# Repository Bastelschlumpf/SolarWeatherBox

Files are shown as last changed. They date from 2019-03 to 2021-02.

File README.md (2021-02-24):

## SolarWeatherBox
  **Iot Weather sensor with solar power and sending the data to an MQTT server.***

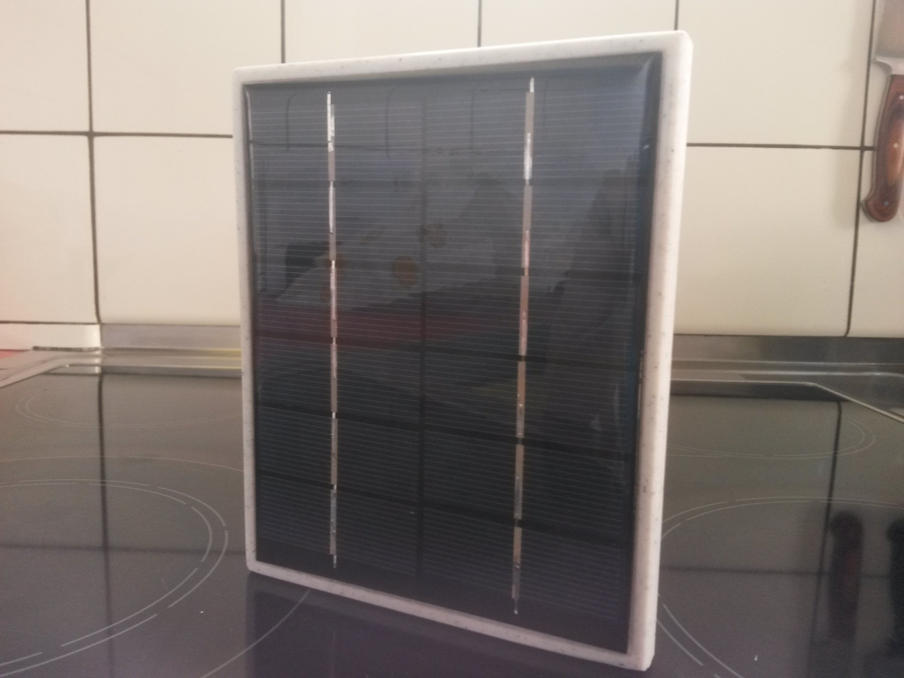
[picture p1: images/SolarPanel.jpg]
SolarPanel
   

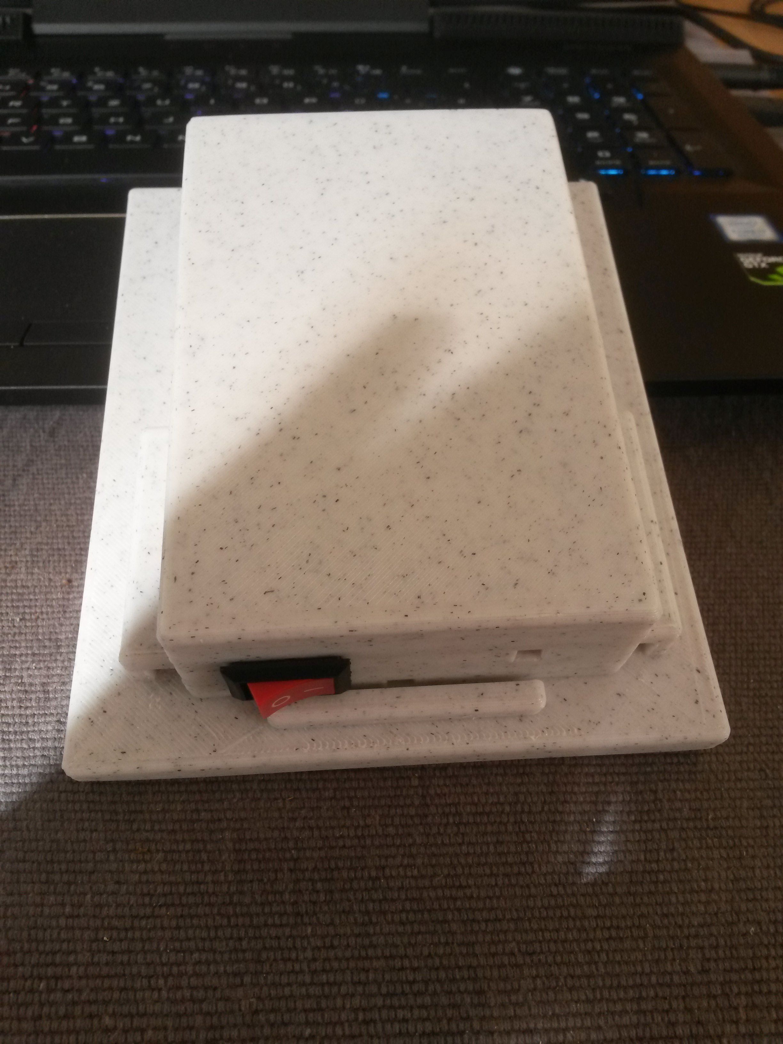
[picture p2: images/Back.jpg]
SolarWeatherBox
   

   SolarWeatherBox BoxInternal

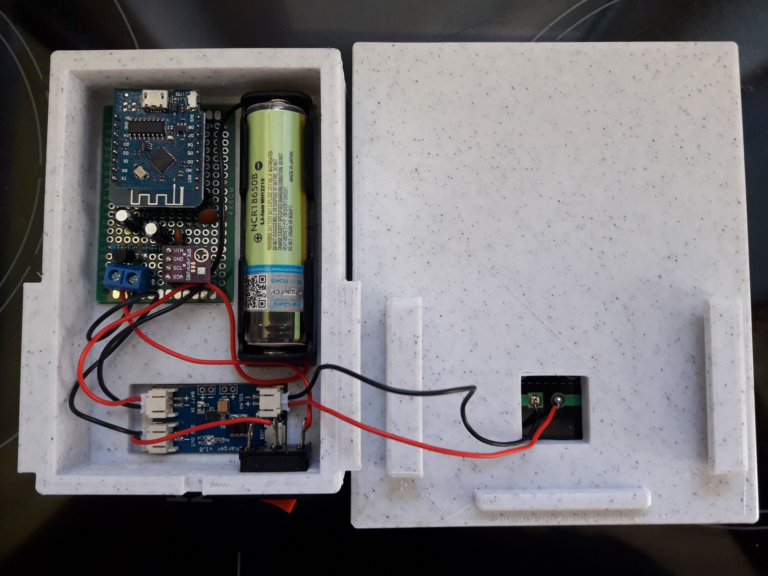
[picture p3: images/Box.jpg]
SolarWeatherBox Box
   

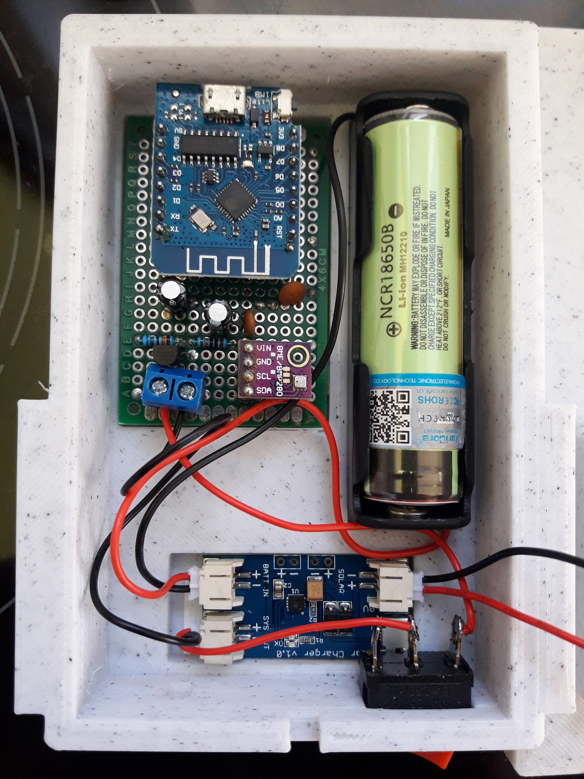
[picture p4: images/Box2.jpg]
SolarWeatherBox Box2
   

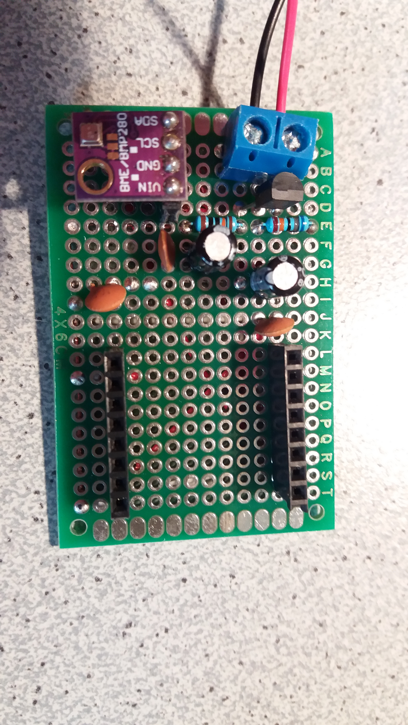
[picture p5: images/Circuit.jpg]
SolarWeatherBox Circuit
   

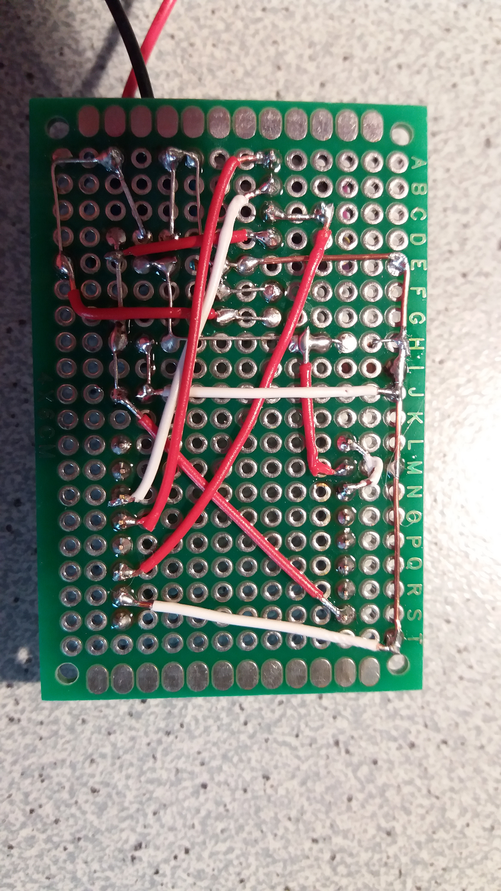
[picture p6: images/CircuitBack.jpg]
SolarWeatherBox CircuitBack
   

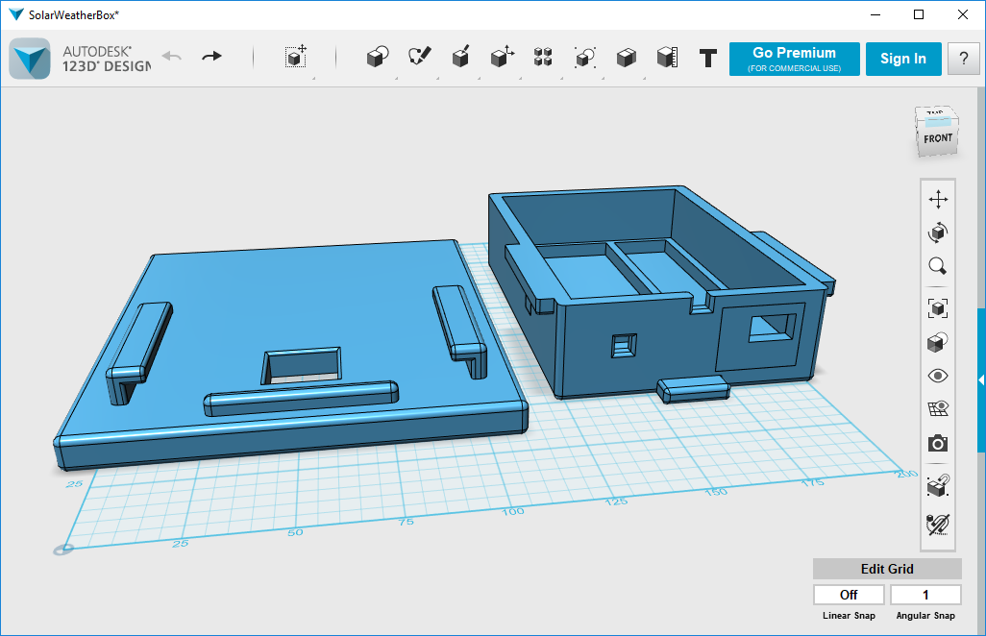
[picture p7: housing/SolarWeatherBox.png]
Housing
   

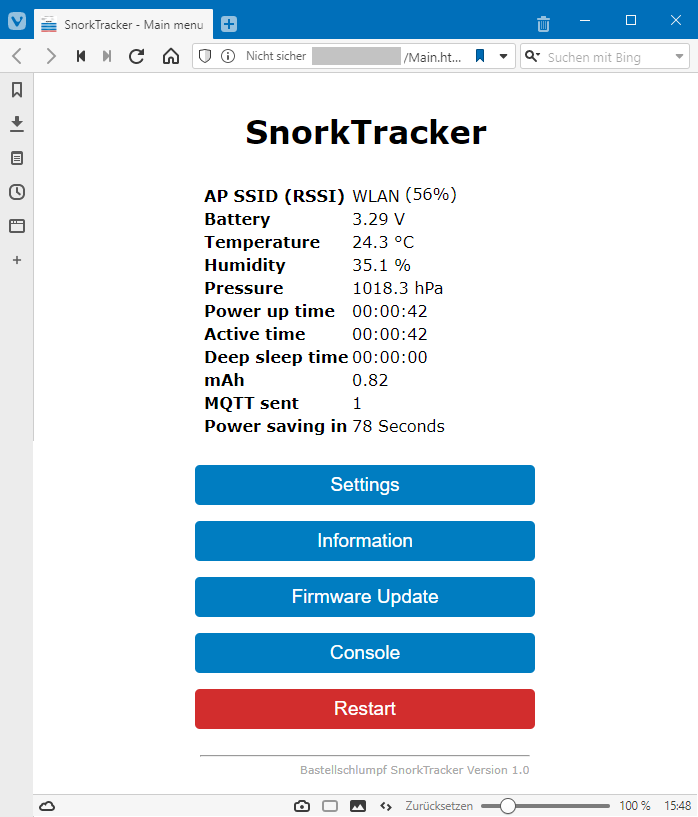
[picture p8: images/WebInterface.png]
Circuit WebInterface
   

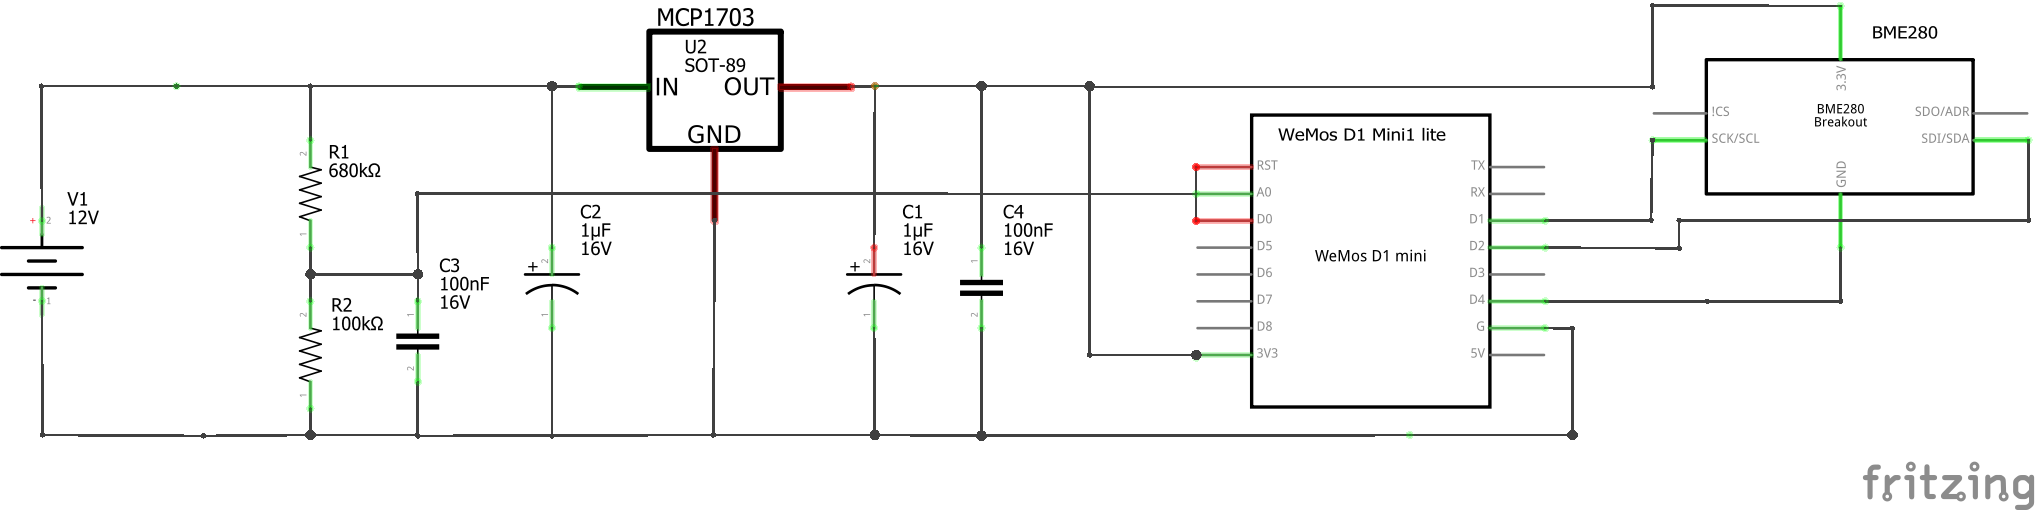
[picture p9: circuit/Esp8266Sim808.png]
Circuit
   

### Description

### Disclaimer
   I don't take any responsibility nor liability for using this software nor for the 
   installation or any tips, advice, videos, etc. given by any member of this site or any related site.

### License
   This program is licensed under GPL-3.0

### Source Code
-  The software is the similar to Snorktracker

### Shopping list
Here are some sample shopping items. Please check the details if everything is correct.

|Label |Price |Sample URL |
|---|---|---|
|Switch |1€ | https://www.bastelgarage.ch/kippschalter-on-off-schalter-6a-125v-3a-250v?search=schal |
|WeMos D1 Mini lite |7€ | https://www.amazon.de/1-0-0-WIFI-Internet-Things-Development-ESP8285/dp/B07JBK1SWQ |
|BME280 |6€ | https://www.amazon.de/AZDelivery-GY-BME280-Barometrischer-Temperatur-Luftfeuchtigkeit/dp/B07FS95JXT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 |
|Li-Ion Akku |12€ | https://www.bastelgarage.ch/li-ion-akku-3000ma-18650-mit-schutzelektronik-und-stecker |
|Solar Set |19€ | https://www.bastelgarage.ch/solar-set-2w-lolin32-mit-laderegler-fur-lipo-akku |

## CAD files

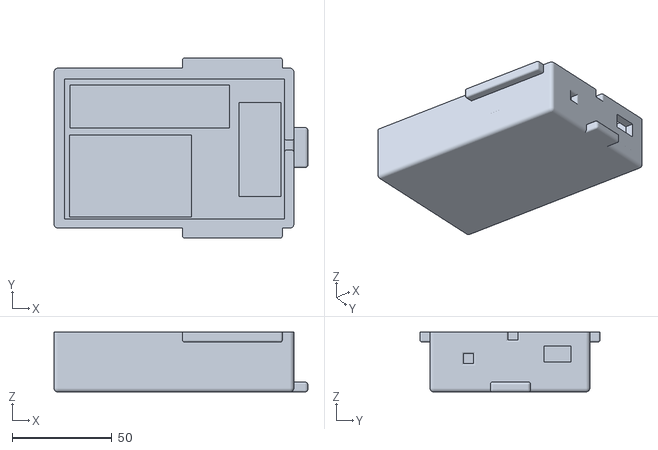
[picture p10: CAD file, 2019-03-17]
housing/SolarBox.stl
127.1 x 90.0 x 30.0

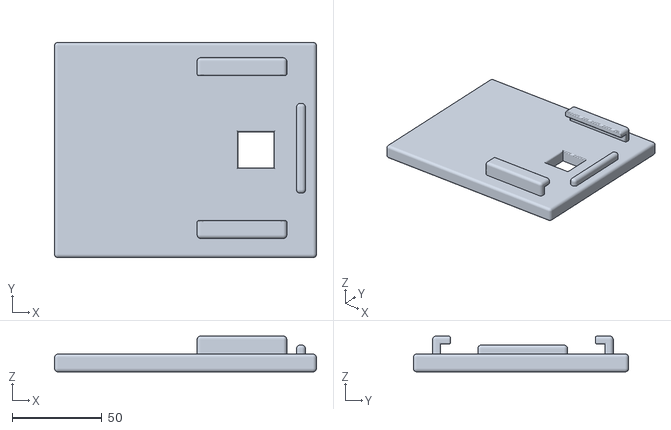
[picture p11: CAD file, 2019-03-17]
housing/SolarPanel.stl
146.0 x 120.0 x 20.0

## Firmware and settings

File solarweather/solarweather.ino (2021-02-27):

/*
   Copyright (C) 2021 SFini

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
   You should have received a copy of the GNU General Public License
   along with this program.  If not, see <http://www.gnu.org/licenses/>.
*/
/**
  * @file tracker.ino 
  *
  * Main file with setup() and loop() functions
  */


#include <SoftwareSerial.h>
#include <ArduinoOTA.h>
#include <FS.h>

#include "Config.h"
#define USE_CONFIG_OVERRIDE //!< Switch to use ConfigOverride
#ifdef USE_CONFIG_OVERRIDE
  #include "ConfigOverride.h"
#endif

#include "Utils.h"
#include "StringList.h"
#include "Options.h"
#include "Data.h"
#include "Voltage.h"
#include "DeepSleep.h"
#include "WebServer.h"
#include "Mqtt.h"
#include "BME280.h"


MyOptions   myOptions;                       //!< The global options.
MyData      myData;                          //!< The global collected data.
MyVoltage   myVoltage   (myOptions, myData); //!< Helper class for deep sleeps.
MyDeepSleep myDeepSleep (myOptions, myData); //!< Helper class for deep sleeps.
MyWebServer myWebServer (myOptions, myData); //!< The Webserver
MyBME280    myBME280    (myOptions, myData); //!< Helper class for the BME280 sensor communication.

MyMqtt      myMqtt(MyWebServer::server.wifiClient(), myOptions, myData); 

bool        isStarting  = false;             //!< Are we in a starting process?
bool        isStopping  = false;             //!< Are we in a stopping process?

/**
 * ***** IMPORTANT *****
 * It seems that the yield function of ESP does not feed the watch dog timer.
 * So we overwrite the yield() function here. If not the program crashed on some waits.
 * ***** IMPORTANT *****
 */
 /*
void yield(void)
{
   ESP.wdtFeed();
}*/

/** Overwritten Debug Function 
  * It logs all the debug calls to the console string-list
  * And call a refresh of the webserver for not blocking the system.
  */
void myDebugInfo(String info, bool fromWebserver, bool newline)
{
   static bool lastNewLine = true;
   
   if (newline || lastNewLine != newline) {
      String secs = String(myData.getActiveTimeSec()) + F(": ");

      myData.logInfos.addTail(secs + info);
      if (!lastNewLine) {
         Serial.println("");
      }
      Serial.println(secs + info);
   } else {
      String tmp = myData.logInfos.removeTail();

      Serial.print(tmp + info);
      myData.logInfos.addTail(tmp + info);
   }
   lastNewLine = newline;

   if (!fromWebserver) {
      myWebServer.handleClient();   
      myWebServer.handleClient();   
      myWebServer.handleClient();   
   } 
   delay(1);
   yield();
}

/** Overwritten delay loop for refreshing the webserver on waiting processes. */
void myDelayLoop()
{
   myWebServer.handleClient();   
   myWebServer.handleClient();   
   myWebServer.handleClient(); 
   delay(1);
   yield();
}

/** Main setup function. This is also called after every deep sleep. 
  * Do the initialization of every sub-component. */
void setup() 
{
   Serial.begin(115200); 
   delay(1000);

   MyDbg(F("Start SolarWeather ..."));

   SPIFFS.begin();
   myOptions.load();

   // Back to deep sleep?
   myDeepSleep.begin();
   if (myDeepSleep.haveToSleep()) {
      myDeepSleep.sleep();
   } else { // no deep sleep!
      myVoltage.begin();
      myWebServer.begin();
      myMqtt.begin();
      myBME280.begin();
   }
}

/** Main loop function.
  * Read the power supply voltage.
  * Checks for OTA activities.
  * Starts the deep sleep mode if needed.
  */
void loop() 
{
   myVoltage.readVoltage();
   myBME280.readValues();
   myDeepSleep.updateTimeToSleep();

   myWebServer.handleClient();
   
   if (myData.isOtaActive) {
      ArduinoOTA.handle();    
   }

   if (myOptions.isMqttEnabled) {
      myMqtt.handleClient();
   }

   if (!myMqtt.waitingForMqtt()) {
      if (myDeepSleep.haveToSleep()) {
         myDeepSleep.sleep();
      }
   }

   yield();
   delay(10); 
}

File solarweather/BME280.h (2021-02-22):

/*
   Copyright (C) 2021 SFini

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
   You should have received a copy of the GNU General Public License
   along with this program.  If not, see <http://www.gnu.org/licenses/>.
*/
/**
  * @file BME280.h
  * 
  * Class to communicate with the BME280 module.
  */


#include <Adafruit_BME280.h>

#define PIN_BME_GRND      D4      //!< Ground pin to the BME280 module

#define BARO_CORR_HPA     34.5879 //!< Correction for 289m above sea level
#define TEMP_CORR_DEGREE  -2.0    //!< The BME280 measure 2 degrees too high 


/**
  * Communication with the BME280 modul to read temperature, humidity and pressure
  */
class MyBME280
{
protected:
   MyOptions      &myOptions;    //!< Reference to global options
   MyData         &myData;       //!< Reference to global data
   int             pinGrnd;      //!< Ground-Pin connection to switch on the BME280 module
   uint8_t         portAddr;     //!< Port address of the bme280
   Adafruit_BME280 bme280;       //!< Adafruit BME280 helper interface
   
public:
   MyBME280(MyOptions &options, MyData &data, int pin = PIN_BME_GRND);

   bool begin();

   bool readValues();
};

/* ******************************************** */

/** Constructor */
MyBME280::MyBME280(MyOptions &options, MyData &data, int pin)
   : pinGrnd(pin)
   , myOptions(options)
   , myData(data)
   , portAddr(0x77)
{
}

/** Switch off the module at startup to safe power. */
bool MyBME280::begin()
{
   pinMode(D1,      INPUT); // I2C SCL Open state to safe power
   pinMode(D2,      INPUT); // I2C SDA Open state to safe power
   pinMode(pinGrnd, OUTPUT);
   digitalWrite(pinGrnd, HIGH); 
   
   if (bme280.begin(0x77)) { // Default 0x77
      portAddr = 0x77;
      MyDbg("BME280 sensor with port 0x77!");
   } else if (bme280.begin(0x76)) { // China 0x76
      portAddr = 0x76;
      MyDbg("BME280 sensor with port 0x76!");
   }
}

/** 
  * Switch on the modul, read the values and switch off the modul to save power. 
  * Do this only every bme280CheckIntervalSec
  */
bool MyBME280::readValues()
{
   if (secondsElapsedAndUpdate(myData.getAllTimeSumSec(), myData.rtcData.lastBme280ReadSec, myOptions.bme280CheckIntervalSec)) {
      digitalWrite(pinGrnd, LOW);
      delay(100); // Short delay after power on
      if (!bme280.begin(portAddr)) {
         myData.temperature = 0;
         myData.humidity    = 0;
         myData.pressure    = 0;
         MyDbg("No valid BME280 sensor, check wiring!");
      } else {
         myData.temperature = bme280.readTemperature() + TEMP_CORR_DEGREE;
         myData.humidity    = bme280.readHumidity();
         myData.pressure    = (bme280.readPressure() / 100.0F) + BARO_CORR_HPA;
         MyDbg("Temperature: " + String(myData.temperature) + "°C");
         MyDbg("Humidity: "    + String(myData.humidity)    + "%");
         MyDbg("Pressure: "    + String(myData.pressure)    + "hPa");
      }
      digitalWrite(pinGrnd, HIGH); 
      pinMode(D1, INPUT); // I2C SCL Open state to safe power
      pinMode(D2, INPUT); // I2C SDA Open state to safe power
   }
}

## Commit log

2019-03-17 SolarWeatherBox with Solar power, MQTT connection and BME280 sensor.
    [Esp8266Sim808.fzz, SolarBox.stl, SolarPanel.stl]
2021-02-14 More accurate voltage
2021-02-14 The BMW sensor use the china port.
2021-02-22 Power checking removed
    Fix deep sleep time
    [BME280.h, Voltage.h]
2021-02-22 Problem with mqtt update
    [BME280.h]
2021-02-23 bug with deep sleep
    [solarweather.ino]
2021-02-25 No On/Off button

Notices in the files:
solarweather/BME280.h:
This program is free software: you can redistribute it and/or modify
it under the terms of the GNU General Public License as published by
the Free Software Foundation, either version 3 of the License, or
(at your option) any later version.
